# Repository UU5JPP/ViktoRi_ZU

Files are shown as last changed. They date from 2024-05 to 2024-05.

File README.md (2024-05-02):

<h2 align="center">Зарядное устройство для аккумуляторных батарей на микроконтроллере Ардуино Viktori</a> </h2>

<h2 align="center">Телеграмм  <a href="https://t.me/arduino_viktori/" target="_blank">чат</a> </h2>
<p align="center">
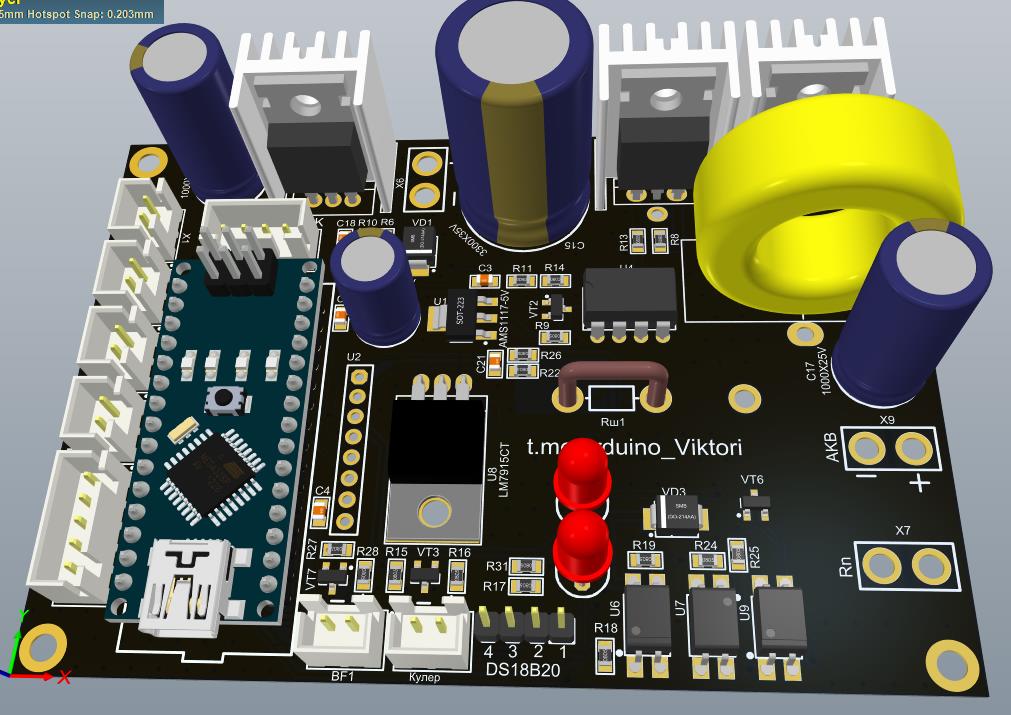
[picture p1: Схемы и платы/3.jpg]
Зарядное устройство

</p>
Общие сведения.<br>
<p>Зарядное устройство ViktoRi является открытым проектом (Open source) со свободным исходным кодом и схемой. Основано на микроконтроллере Atmega 328P (Arduino Nano, UNO,…) , LGT8F328P. Предназначено для заряда аккумуляторных батарей (в дальнейшем — АКБ) свинцово-кислотных, AGM, GEL, литий-ионных, литий-титанатных, никель-кадмиевых напряжением 3 — 24 Вольт и емкостью 1 ... 255 Ач, применяемых на автомобилях, мотоциклах, катерах, скутерах, ИБП  и т. д.</p>

<p>Зарядное устройства ViktoRi имеет жидкокристаллический дисплей 16*2 либо 20*4, на котором отображаются текущие параметры заряда, настраиваемые параметры и информационные сообщения. Для управления применяется Энкодер и кнопки.</p><br>
<p>Зарядное устройство реализует несколько алгоритмов заряда, включающий: 
  <ul>
 <li> предварительный заряд сильно разряженного аккумулятора;</li>
 <li>  основной заряд комбинированным методом (стабилизация тока на этапе основного заряда с переключением в режим стабилизации напряжения на конечном этапе); </li>
 <li>  режим качели в конце основного заряда; </li>
 <li>  дозаряд батареи;  режим безопасного хранения батареи с поддержанием заряда; Имеется режим разряда, измерения внутреннего сопротивления, проведение контрольно-тренировочных циклов (в дальнейшем КТЦ), заряд аккумулятора по методике Бранимира (заряд малыми токами).</li>
  </ul>
Во время работы зарядное устройство контролирует и регулирует напряжение на АКБ, ток заряда/разряда. Рассчитываются и сохраняются в память Ампер/часы, Ватт/часы.</p>

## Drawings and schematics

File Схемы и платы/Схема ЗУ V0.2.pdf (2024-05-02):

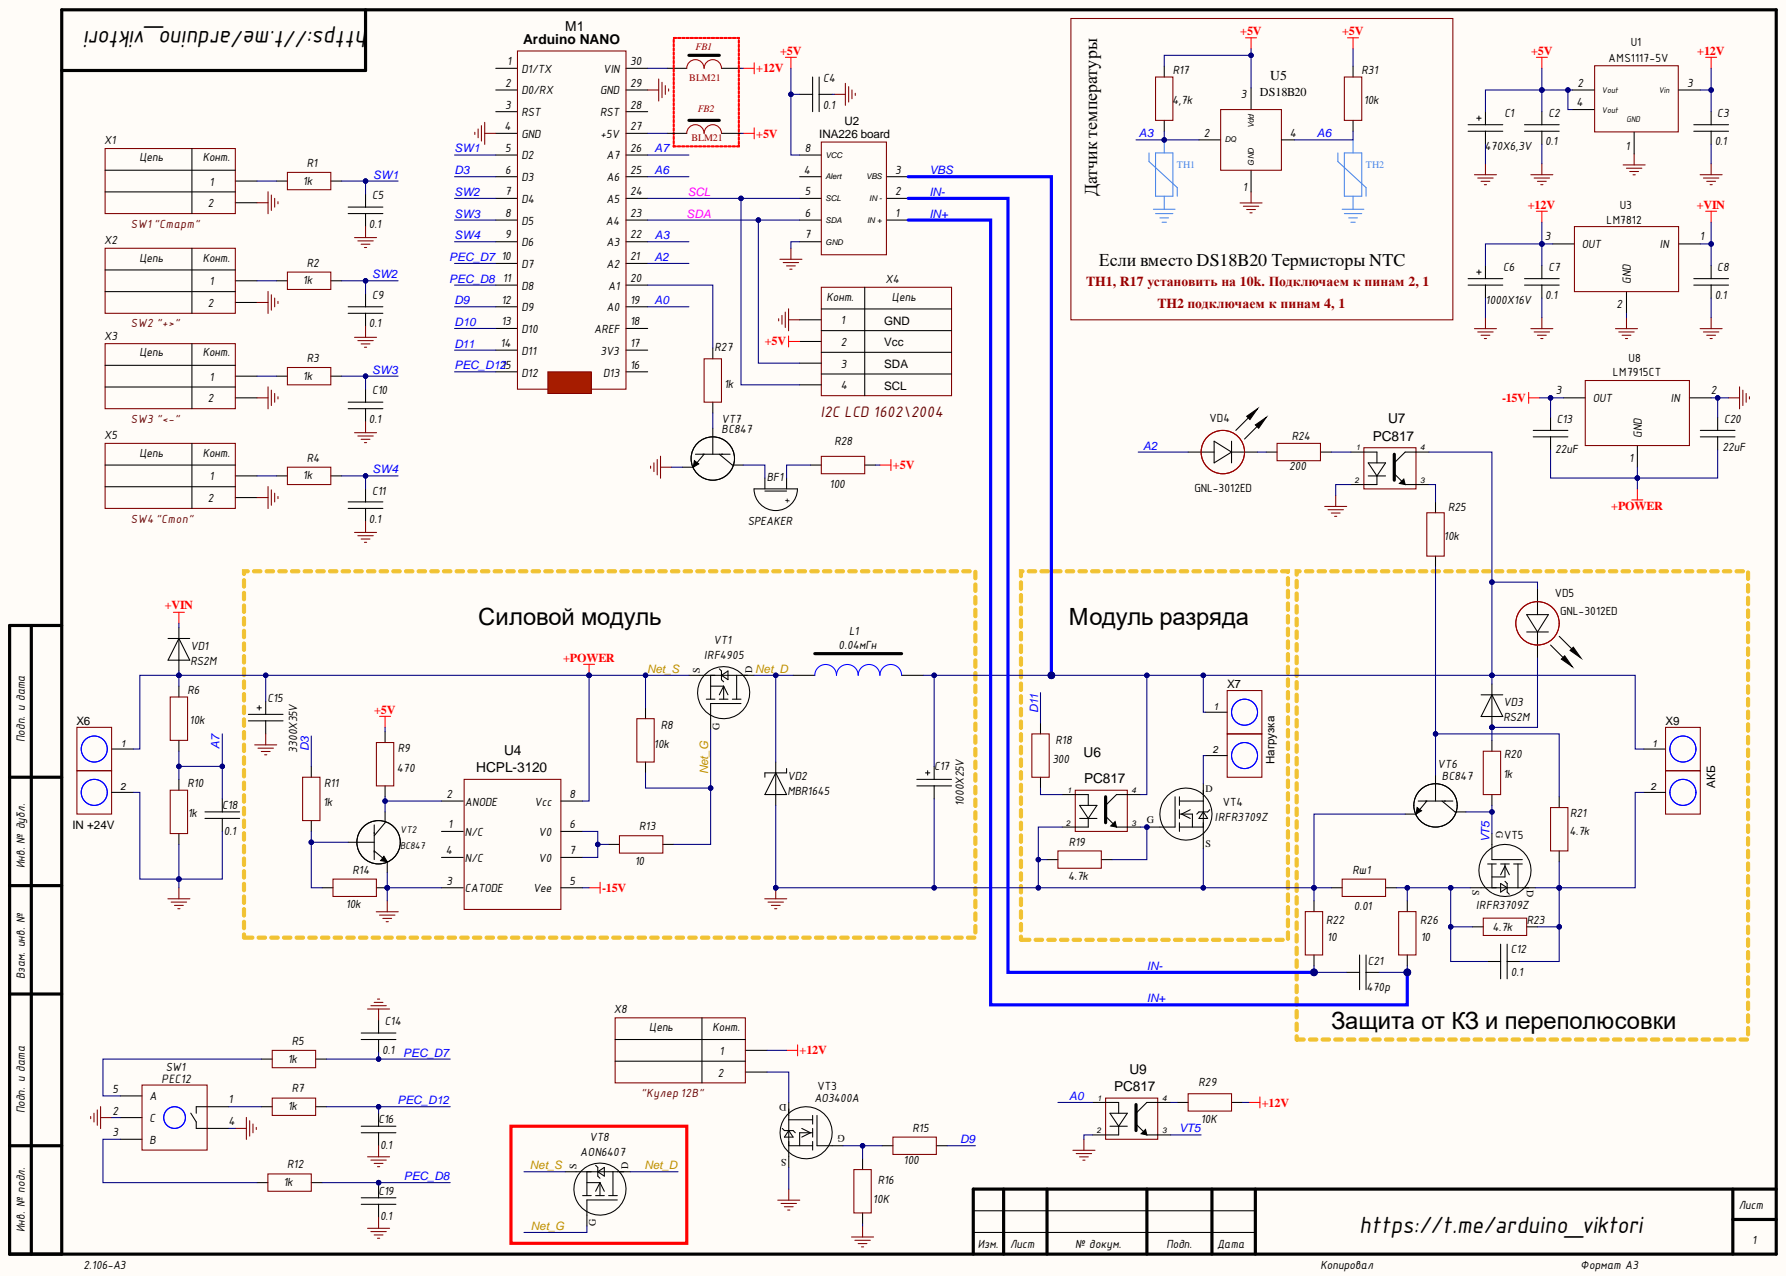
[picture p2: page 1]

Если вместо DS18B20 Термисторы NTC

2 | Vcc

3 | SDA

4 | SCL

Цепь | Конт.

Инв. № подл. Инв. № дубл. Подп. и дата Взам. инв. № Подп. и дата

Защита от КЗ и переполюсовки

Comment | Description | Designator | Footprint | LibRef | Quantity
SPEAKER | | BF1 | CON: CWF-2 | Buzzer | 1
470X6,3V | | C1 | D8C3.5H12 | AlumCap | 1
0.1 | | C2, C3, C4, C5, C7, C8, C9, C10, C11, C12, C14, C16, C18, C19 | CH0805C | Capacitor | 14
1000X16V | | C6 | D10C5H20 | AlumCap | 1
22uF | | C13, C20 | CH1206C | Capacitor | 2
3300X35V | | C15 | D16C7.5H25 | AlumCap | 1
1000X25V | | C17 | D10C5H20 | AlumCap | 1
470p | | C21 | CH0805C | Capacitor | 1
BLM21 | | FB1, FB2 | CH0805L | FB-1 | 2
0.04мГн | | L1 | POWER_L | TRANS | 1
Arduino NANO | | M1 | ARDUINO NANA | Arduino nano | 1
1k | | R1, R2, R3, R4, R5, R7, R10, R11, R12, R20, R27 | CH0805R | Resistor | 11
10k | | R6, R8, R14, R16, R25, R29, R31 | CH0805R | Resistor | 7
470 | | R9 | CH0805R | Resistor | 1
10 | | R13, R22, R26 | CH0805R | Resistor | 3
100 | | R15, R28 | CH0805R | Resistor | 2
4,7k | | R17 | CH0805R | Resistor | 1
300 | | R18 | CH0805R | Resistor | 1
4.7k | | R19, R21, R23 | CH0805R | Resistor | 3
200 | | R24 | CH0805R | Resistor | 1
0.01 | | Rш1 | HUNT 10mm | Resistor | 1
PEC12 | Encoder | SW1 | CON: CWF-5 | PEC12 | 1
AMS1117-5V | | U1 | SOT223 | AMS117 | 1
INA226 board | | U2 | CON: PBS-8 | INA226 | 1
LM7812 | | U3 | TO220_123 | 7809 | 1
HCPL-3120 | | U4 | DIP-8 | HCPL-3120 | 1
DS18B20 | | U5 | CON: PLS-4 | DS18B20_V1 | 1
PC817 | | U6, U7, U9 | PC817-SMD | PC817 | 3
LM7915CT | | U8 | TO-220_90 | 7809 | 1
RS2M | | VD1, VD3 | SMB | Diod | 2
MBR1645 | | VD2 | TO-220_2pin | Diod Schottky | 1
GNL-3012ED | | VD4, VD5 | DIOD: LED5MM_R | LED | 2
IRF4905 | | VT1 | TO220_123_V | P-KANAL | 1
BC847 | | VT2, VT6, VT7 | SOT23_123 | N-P-N | 3
AO3400A | | VT3 | SOT23_132 | N-KANAL | 1
IRFR3709Z | | VT4, VT5 | D2PAK | N-KANAL | 2
AON6407 | | VT8 | DFN5x6 | P-KANAL | 1
SW1 "Старт" | | X1 | CON: CWF-2 | 2-Connector | 1
SW2 "+>" | | X2 | CON: CWF-2 | 2-Connector | 1
SW3 "<-" | | X3 | CON: CWF-2 | 2-Connector | 1
I2C LCD 1602\2004 | | X4 | CON: CWF-4 | 4-Connector | 1
SW4 "Стоп" | | X5 | CON: CWF-2 | 2-Connector | 1
IN +24V | | X6 | CON: 2P_5mm | 2-CON | 1
Нагрузка | | X7 | CON: 2P_5mm | 2-CON | 1
"Кулер 12В" | | X8 | CON: CWF-2 | 2-Connector | 1
АКБ | | X9 | CON: 2P_5mm | 2-CON | 1

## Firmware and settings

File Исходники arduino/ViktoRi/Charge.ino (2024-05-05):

/*
флаги управления зарядом
CHARGEZ 0  // заряд включен
OSCILZ 1   // осциляция
KORR 2     // корректировка напряжения и тока заряда
KORRVA 3   // изменение вольт или ампер
VMAXM 4    // напряжение достигло максимума
*/

struct VA_var {
  uint16_t vmax[13] = { 0 };  // 13 значения напряжения. Сохраняются каждые 5 минут.
  int16_t amin[13] = { 0 };   // 13 значения тока

  void sred_v(void) {
    vmax[12] += (((int16_t)ina.voltsec - (int16_t)vmax[12]) >> 2);
  }
  void sred_a(void) {
    amin[12] += ((ina.ampersec - amin[12]) >> 2);
  }

  void sred_va(void) {
    sred_v();
    sred_a();
  }

  void offset(void) {
    // сохранить 12 значений напряжения и тока за 1 час
    // смещение значений на одно влево
    for (uint8_t n = 1; n < 12; n++) {
      vmax[n] = vmax[n + 1];
      amin[n] = amin[n + 1];
    }
  }
#if (GRAFIK == 1)
  void grafik(void) {
    // 1 - найти мин и макс
    int16_t vmin = vmax[1];
    int16_t vmks = vmax[1];
    int16_t amnm = amin[1];
    int16_t amks = amin[1];
    for (uint8_t n = 2; n <= 12; n++) {
      if (vmax[n] and (vmin > (int16_t)vmax[n])) vmin = (int16_t)vmax[n];  // миним напр
      if (vmax[n] and (vmks < (int16_t)vmax[n])) vmks = (int16_t)vmax[n];  // максим напр
      if (amin[n] and (amnm > amin[n])) amnm = amin[n];                    // миним ток
      if (amin[n] and (amks < amin[n])) amks = amin[n];                    // макс ток
    }
    // найти разницу
    int16_t vraznica = vmks - vmin;
    int16_t araznica = amks - amnm;
    // 2 - найти разрешение
    int16_t vrazr = (vraznica > 700) ? vraznica : 700;
    int16_t arazr = (araznica > 700) ? araznica : ((amks <= 200 and araznica <= 200) ? 400 : 700);

    // 3 - найти минимальное значение
    vmin -= ((vrazr - vraznica) >> 1);
    amnm -= ((arazr - araznica) >> 1);
    if (vmin < 0) vmin = 0;
    if (amnm < 0) amnm = 0;
    // 4 - найти максимальное значение
    vmks = (vmin) ? vmks + ((vrazr - vraznica) >> 1) : vrazr;
    amks = (amnm) ? amks + ((arazr - araznica) >> 1) : arazr;

    for (uint8_t n = 1; n <= 12; n++) {  // вывод на дисплей
      if (vmax[n]) {
        lcd.setCursor(n - 1, 0);
        lcd.write(map(vmax[n], vmin, vmks, 0, 6));
        lcd.setCursor(n - 1, 1);
        lcd.write(map(amin[n], amnm, amks, 0, 6));
      }
    }
    lcd.setCursor(12, 0);
    lcd.print(F(txt22));  // Volt
    lcd.setCursor(12, 1);
    lcd.print(F(txt23));  // Amper
  }
#endif
};

struct Tyme {
  uint32_t local;    // сюда сохраняем время заряда из памяти в сек (при запуске заряда)
  uint32_t real;     // сюда сохраняем начальный таймер заряда в мс (при запуске заряда)
  uint32_t real_tm;  // сюда рассчитывается полное время заряда (каждую секунду)

  void cal_real_tm(void) {
    real_tm = local + (millis() - real) / 1000;  // рассчитать количество всех секунд заряда (каждую секунду)
  }
};

// Функция заряда. volt_charge_init - напряжение заряда, curr_charge_init - ток заряда, curr_min - минимальный ток заряда, time_charge - время заряда в часах, add_charge - дозаряд вкл/откл
void ChargeAkb(uint16_t volt_charge_init, int16_t curr_charge_init, int16_t curr_min, uint32_t time_charge, bool add_charge) {
  enum {CHARGEZ = 0, OSCILZ, KORR, KORRVA, POWOFF, VMAXM};
  uint8_t flagsz = 0b00001011;  // флаги
  //вывод режима, напряжения и тока заряда/разряда
#if (GUARDA0)
  Guard();  // принудительная блокировка модуля защиты при напряжении заряда или разряда акб менее 5 Вольт.
#endif
  // вывод значений заряда
  PrintVA(volt_charge_init, curr_charge_init, 0, 0, 1);  // вывод напряжения и тока заряда
  lcd.print(time_charge);                                // вывод времени заряда/дозаряда
  lcd.write(104);                                        // h
  lcd.setCursor(DISPLAYx - 2, 0);
  printCykl();  // вывод количества циклов
  Freq(EEPROM.read(8 + FREQCHARGE));  // установить частоту работы силового модуля
  time_charge *= 3600;  // перевел часы в секунды

  VA_var va;
  Tyme tyme;

  tyme.local = add_charge ? pam.Time_addcharge : pam.Time_charge;

  const uint8_t VoltinKooff = bat.Volt(1) >> 8;                             // 14700/256 = 57 // pam.Voltage * 15; // количество банок * 15мВ;  // 4*15=60
  uint8_t typez = add_charge ? 3 : (bitRead(pam.MyFlag, PRECHAR) ? 1 : 2);  // 1 - Предзаряд, 2 - Заряд, 3 - Дозаряд (4 - осциляция(качели)), 5 - заряд по Бранимиру
#if (BRANIMIR == 1)
  if (pam.Mode == 2) typez = 5;  // 5 - заряд по Бранимиру
  uint32_t tyme_branim = 0;
#endif
  uint8_t ap[2] = { 4, 15 };  // коэффициент тока для предзаряда
  // задает напряжение и ток заряда
  dcdc.begin(volt_charge_init, (add_charge ? curr_charge_init : (bitRead(pam.MyFlag, PRECHAR) ? pam.Current_pre_charge : curr_charge_init)));

  uint8_t n_disp = 0, ns_disp = 0;  // номер 'экрана, время отображения
  uint16_t Timezar = 0;             // время до завершения заряда секунды
  uint16_t v1 = 0;                  // переменная для сохранения напряжения
  uint8_t tsw = 10;                 // Дозаряд переменная времени переключения, сек.
  uint8_t timeaut10 = 2;            // время 10 минут
  uint16_t timeaut5 = 300;          // время 5 минут
  uint8_t time_millis = 0;
  uint16_t volt_init;
  const int16_t cur_max = curr_charge_init;
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

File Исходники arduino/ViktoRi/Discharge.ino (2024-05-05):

#if (DISCHAR == 1)
//Функция разряда аккумулятора
void Discharge() {  
  //вывод режима, напряжения и тока заряда/разряда
  PrintVA(pam.Volt_discharge, pam.Current_discharge, 0, 0, 1);  // напряжения и тока разряда
  printCykl();                                                  // вывод количества циклов
  Freq(EEPROM.read(8 + FREQDISCHAR));                           // установить частоту работы разрядного модуля (4 кГц по умолчанию)
  const uint16_t s1 = ina.voltsec;                              // текущее наряжение акб;
  uint8_t tok = 1, n_disp = 0, ns_disp = 0;
  bool dischar = true;  // разряд включен

  uint8_t time_millis = 0;
  Tyme tyme;
  tyme.local = pam.Time_discharge;  
  dcdc.begin(pam.Volt_discharge, pam.Current_discharge); // задает напряжение и ток разряда

#if (LOGGER)
  uint8_t logg = LOGGTIME;  // период отправки данных в сетевой порт
#endif
  ina.start(2);           // старт замеров INA
  Delay(3000);

#if (POWPIN == 1)
  bitSet(flag_global, RELEY_OFF);  // разрешено отключать реле
#endif
  uint16_t time10 = 600;  // выполнить раз в 600 сек (10 мин)
  sekd.start();           // старт отсчета времени одна секунда
  
  dcdc.start(DCDC_DISCHARGE);
  tyme.real = millis();  // запоминаем текущее время
  // цикл разряда 35 часов максимум
  while (dischar and bitRead(pam.MyFlag, CHARGE) and pam.Time_discharge < 126000) {
    sensor_survey();  // опрос кнопок, INA226, напря. от БП., контроль dcdc.

    if (butt.tick) {
      // если кнопка нажата
      switch (butt.tick) {
        case ENCHELD:                    // удержать энкодер
        case STOPHELD:                   // удержать Стоп
          bitClear(pam.MyFlag, CHARGE);  // завершить разряд
          break;
        case RIGHT:             // энкодер вправо
        case LEFT:              // энкодер влево
          n_disp++;             // окно отображения
          ns_disp = TIME_DISP;  // время отображения сек
          lcd.clear();
          break;
      }
    }

    if (sekd.tick()) time_millis = 5;

    // если прошла секунда
    if (time_millis) {
      switch (time_millis) {
        case 5:
          {
            int16_t ampsec = abs(ina.ampersec);
            pam.Ah_discharge += aw_ch((int32_t)ampsec);      // расчет ампер/часов
            pam.Wh_discharge += aw_ch(abs(ina.getPower()));  // расчет ватт/часов
            tyme.cal_real_tm();                              // рассчитать количество всех секунд разряда
            pam.Time_discharge = tyme.real_tm;

            if (ina.voltsec <= pam.Volt_discharge and ampsec <= pam.Current_discharge_min) dischar = false;  // напряжение уменьшилось до установленного и ток уменьшился до установленного то завершить разряд
          }
          break;
          //       case 4:

          //          break;
        case 3:
          // вывод на дисплей 1602
#if (DISPLAYy == 2)
          switch (n_disp) {
              // вывод на дисплей
            case 0:
              // экран 0 // вывод текущих значений напряжения, тока. Вывод Ватт-часов.
              Display_print(pam.Ah_discharge, pam.Time_discharge, map(ina.voltsec, pam.Volt_discharge, s1, 0, 100), false);  // вывод на дисплей
              break;
            case 1:
              // экран 1 // вывод средних значений напряжения, тока. Вывод Ватт-часов.
              setCursorx();
              print_mode(0);
              printSimb();
              printCykl();
              setCursory();
              PrintVA(0, 0, 0, pam.Wh_discharge, 2);
              lcd.print(map(ina.voltsec, pam.Volt_discharge, s1, 0, 100));
              lcd.print(F(txt_PRC));
#if (SENSTEMP1)
              print_tr(kul.tQ1);  // температура
#endif
#if (SENSTEMP2 == 2)
              print_tr(ntc.akb);  // температура акб
#endif
                // print_memoryFree(); // вывод свободной оперативки
              if (ns_disp) ns_disp--;
              else n_disp = 0;
              break;
              // *Discharge C1 N1 *
              // *45.25Wh 45%     *
            default:
              n_disp = 0;
              break;
          }
// вывод на дисплей 2004 или 1604
#elif (DISPLAYy == 4)
          // вывод на дисплей
          switch (n_disp) {
            case 0:
              // экран 0  вывод текущих значений
              Display_print(pam.Ah_discharge, pam.Wh_discharge, pam.Time_discharge, kul.tQ1, map(ina.voltsec, pam.Volt_discharge, s1, 0, 100));
              break;
            case 1:
              // экран 1
              setCursorx();
              print_mode(0);
              printSimb();
              printCykl();
              setCursory();
#if (SENSTEMP1)
              print_tr(kul.tQ1);  // температура
#endif
#if (SENSTEMP2 == 2)
              print_tr(ntc.akb);  // температура акб
#endif
              if (ns_disp) ns_disp--;
              else n_disp = 0;
              break;
            default:
              n_disp = 0;
              break;
          }
#endif
          break;

        case 2:
#if (TIME_LIGHT)
          disp.Light_low();  // отключение подсветки через 3 минуты, если разрешено отключение
#endif
          break;
        case 1:
#if (GUARDA0)
          Guard();  // принудительная блокировка модуля защиты при напряжении заряда или разряда акб менее 5 Вольт.
#endif
#if (LOGGER)
          logg--;
          if (!logg) {
            logg = LOGGTIME;
            Serial_out(pam.Ah_discharge);
          }
#endif

          time10--;
          // выполнить раз в 10 мин
          if (!time10) {
            time10 = 600;
            Saved();  // сохранить настройки
          }
          break;
      }
      time_millis--;
    }
    // выполнить раз в секунду
  }
  // цикл разряда
  dcdc.Off();  // отключить заряд, разряд.
#if (GUARDA0)
  gio::low(PINA0);
#endif
  Saved();  // сохранить настройки
}
// Функция разряда аккумулятора
#endif
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

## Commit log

2024-05-02 Гербер и схема
2024-05-02 Исходник в Altium Designer
    [Зарядное для АКБ.PrjPcb, Схема ЗУ.SchDoc]
2024-05-02 Инструкция
2024-05-02 Описание
2024-05-03 1.3 тест 8
    - исправил замер измерения сопротивления акб;
    - исправил контроль температуры Акб;
    - оптимизация класса управления ШИМ заряда/разряда (DCDC.h);
    [1_User_Setup.h, 3_Menu-1602.ino, Charge.ino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]
2024-07-05 1.32 тест 1
    - исправления в интерфейсе;
    - добавил поддержку датчиков температуры 18b20 для аккумулятора(для LGT8F328);
    - изменил проверку силового транзистора на пробой;
    - полностью изменил алгоритм работы с АЦП ардуинки.
    Использовал библиотеку directADC.h.
    Теперь программа не ждет результат работы АЦП, а берет результат преобразования когда он будет готов.
    Считывание значений напряжения БП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
    [1_User_Setup.h, 2_menu.h, 3_Menu-1602.ino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]
